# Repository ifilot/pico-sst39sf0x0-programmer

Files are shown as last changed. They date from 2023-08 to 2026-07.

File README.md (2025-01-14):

# PICO-SST39SF0x0 Programmer






OSHW (https://certification.oshwa.org/nl000020.html)

> [!NOTE]  
> Wish to buy an assembled device? Feel free to contact me at ivo@ivofilot.nl. Price will be around €20,00. Will ship from the Netherlands.

> [!TIP]
> There also exists [a command-line tool](https://github.com/ifilot/pico-flasher-cli) to interface with the PICO-SST39SF0x0 Programmer.

> [!CAUTION]  
> Whenever possible, avoid using USB hubs to connect your **PICO-SST39SF0x0 Programmer**. 
> USB hubs can sometimes cause instability in the serial connection, which may 
> lead to crashes or unexpected program behavior.

## Obtaining pre-built binaries

Download the latest version of the binaries via the links below.

* [Firmware PICO (.uf2 file)](https://github.com/ifilot/pico-sst39sf0x0-programmer/releases/latest/download/pico-sst39sf0x0-programmer-firmware.uf2)
* [Firmware PICO2 (.uf2 file)](https://github.com/ifilot/pico-sst39sf0x0-programmer/releases/latest/download/pico2-sst39sf0x0-programmer-firmware.uf2)
* [GUI Installer](https://github.com/ifilot/pico-sst39sf0x0-programmer/releases/latest/download/pico-sst39sf0x0-programmer-installer-win64.exe)

## Purpose

This open hardware project aims users to produce a low-cost flasher for the
[SST39SF0x0 type](https://ww1.microchip.com/downloads/en/DeviceDoc/20005022C.pdf) 
of ROM chips. The flasher revolves around the cheap
[Raspberry PICO](https://www.raspberrypi.com/products/raspberry-pi-pico/) device.

Besides general read/write/erase functionality for the SST39SF0x0 type of ROM
chips, the software and tools delivered with the PICO-SST39SF0x0 Programmer tend
to cater to a number of projects involving the venerable 
[P2000T and P2000M](https://en.wikipedia.org/wiki/Philips_P2000), both early 
Philips home computers of the 1980s. See the list below for the projects that
use the PICO-SST39SF0x0 Programmer flasher.

* [P2000T Cartridges](https://github.com/ifilot/p2000t-cartridges): A set of
  homebrew cartridges designed for the P2000T. These cartridges all use
  SST39SF0x0 type of ROM chips.
* C64 Multirom

Nevertheless, this is a general purpose product and you are able to flash and
kind of data onto the ROM chips.

> [!TIP]  
> If you do not like seeing these ROM files being displayed, you can hide them
> via `Edit > Settings`.

## Device

The fully assembled device will look as seen in the image below. A ZIF-style
socket is used to insert the SST39SF0x0 chip. A reset button button is exposed
which will reset the device. The green and red LEDs will be on during read and
write operations, respectively. At the top-right part of the device, an access
hole is made to insert a long thin wire to press on the `bootsel` button of the
Raspberry Pi PICO. When this button is pressed down and a USB cable is inserted,
the PICO will expose a file system allowing the user to upload the firmware
to the device.

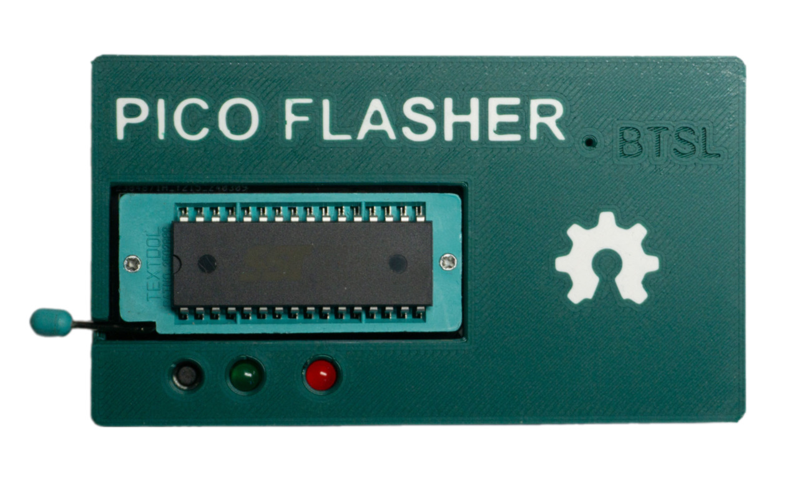
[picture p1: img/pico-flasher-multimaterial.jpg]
Image of the PICO Flasher device


Inside the enclosure is a single PCB that hosts the PICO, the ZIF cartridge
and a number of chips. Since the GPIO pins on the PICO are 3.3V, extensive use
of level shifters is made to hook up the PICO to the SST39SF0x0 chip, whose
pins operate at the 5V logic level. To set the address on the SST39SF0x0 chip,
three 74HC573 chips are being used (U2-U4). A diode (D1) acts as the reverse
polarity protection in the event the user would place the chip in the wrong
direction.

PCB frontside | PCB backside
------------- | ------------
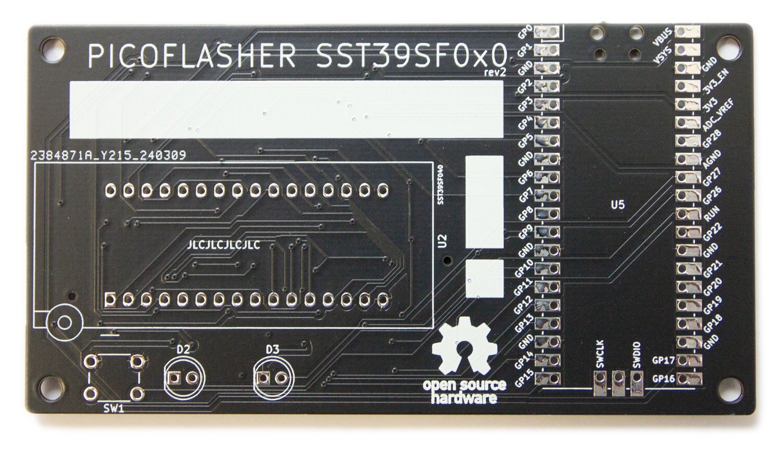
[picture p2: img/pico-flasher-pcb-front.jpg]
PCB frontside
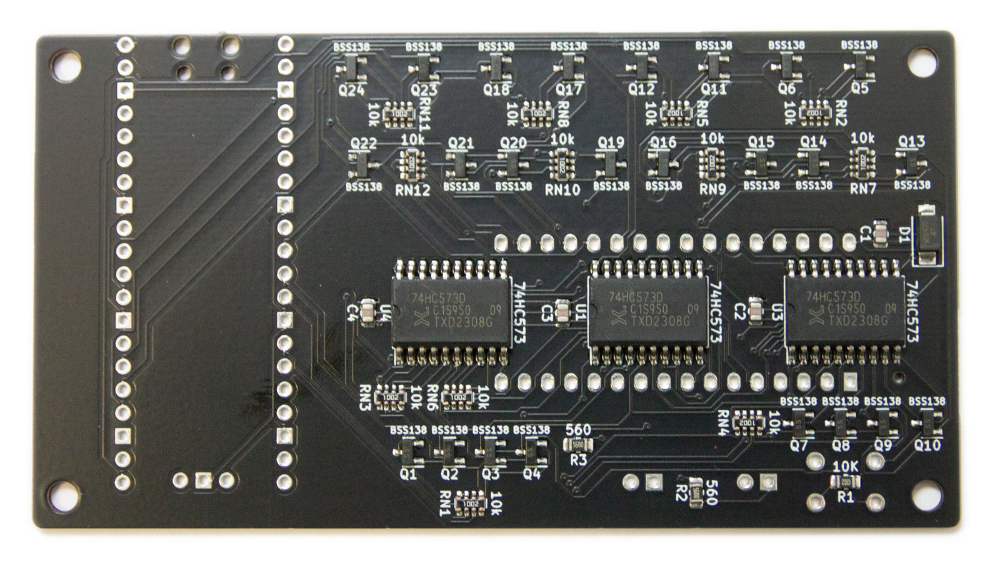
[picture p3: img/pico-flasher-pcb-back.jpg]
PCB backside
 | 

## GUI

To interface with the device, a GUI is written using the 
[Qt framework](https://www.qt.io/). The GUI scans for all USB devices connected
to the computer with a hardware signature matching the Raspberry Pi PICO. Upon
a match, it tries to access the device. Interfacing with the device occurs via
a [serial communication (COM) port](https://en.wikipedia.org/wiki/COM_(hardware_interface)).
By means of a number of [simple 8-byte command words](firmware/README.md),
instructions can be sent to the device and the corresponding response can be
received. One is not restricted to using the GUI to interface with the device.
An [example set of Python scripts](firmware/scripts) is provided to provide 
an alternative way to communicate with the PICO programmer.

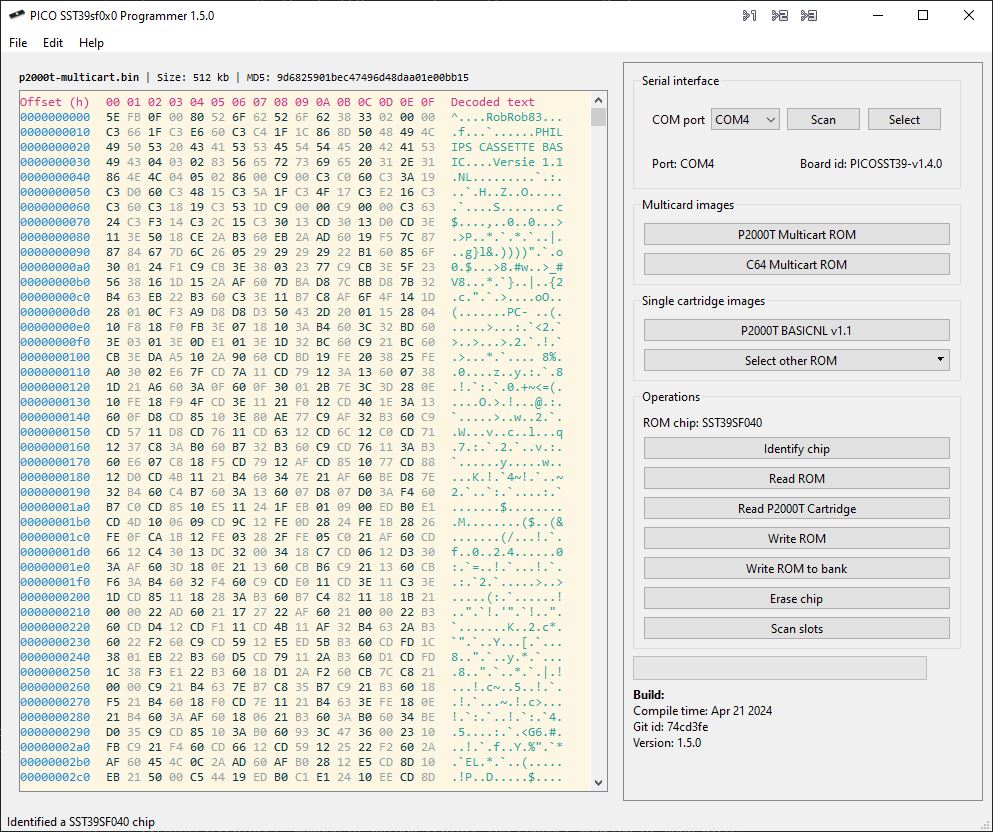
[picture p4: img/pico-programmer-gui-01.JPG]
PICO programmer GUI


> [!NOTE]  
> There is also a command-line tool available via
> [this repository](https://github.com/ifilot/pico-flasher-cli).

## Documentation and tutorials

A number of useful tutorials to work with the PICO programmer are provided
below.

* [Flashing the device / updating firmware](https://www.philips-p2000t.nl/tools/pico-sst39sf0x0-programmer.html#flashing-firmware-to-the-programmer)
* [Using the programmer to create copies of P2000T cartridges](https://www.philips-p2000t.nl/tools/pico-sst39sf0x0-programmer-slot1-adapter-board.html)
* [Using the PICO programmer in combination with the P2000T ZIF-cartridge](https://www.philips-p2000t.nl/cartridges/zif-cartridge.html#zif-cartridge)

## Schematics

PCB schematics

[Download schematics as PDF](pcb/pico-sst39sf0x0-pcb/pico-sst39sf0x0-pcb.pdf)

## Contents

* [Case](case): Set of .stl files to print a handy case for your flash device.
* [Firmware](firmware): Firmware for your PICO to interface with the GUI.
* [GUI](gui): Qt-based GUI to interface with your PICO.
* [PCB](pcb): Kicad files to produce the PICO flash device and the PLCC32 adapter board.
* [Scripts](scripts): Number of Python scripts the correct working of your PICO
  device.

## License

* All software is shared under the [GPL v3 license](https://www.gnu.org/licenses/gpl-3.0).
* All hardware (e.g. KiCAD files and .stl files) are shared under the [CC-BY-SA 4.0 license](https://creativecommons.org/licenses/by-sa/4.0/).

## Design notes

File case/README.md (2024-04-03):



# PICO-SST39SF0x0 Programmer Cases

This folder contains .stl files to create a nice 3d-printable case for your
rom flasher. The files are marked as `bottom` or `top` for the bottom and
top parts of the case. You will need 4xM3 screws to fasten everything together.

The STL files have cylinders (10mm width; 0.3mm height) attached to
the corners to prevent warping of the object upon printing. These spheres
are called [mouse ears](https://the3dprinterbee.com/mouse-ears-brim-ears/).

## Recommended printer settings

* Layer height: 0.15mm
* Infill: 20%
* Fill pattern: grid

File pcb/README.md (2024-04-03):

# PCBs



This folder contains three subfolders containing the KiCAD files for three
PCBs

* [pico-sst39sf0x0-pcb](pico-sst39sf0x0-pcb): Core PCB containing the Raspberry
  Pi PICO, the ZIF socket and the required interfacing circuitry.
* [p2000t-slot1-adapter-board](p2000t-slot1-adapter-board): Adapter board for
  non-invasive extraction of data from SLOT1 cartridges for the P2000T
* [plcc32-adapter-board](plcc32-adapter-board): Adapter board for interfacing
  the DIP32 SST39SF0x0 chips with the PLCC32 variant.

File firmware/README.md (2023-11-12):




# PICO Firmware

This folder contains the firmware for the PICO.

## Compilation

```
mkdir build-firmware
cd build-firmware
cmake ../firmware
make -j9
```

Next, copy the `sst39sf040.uf2` file from the `build` folder to your PICO.

## Toolchain

First install the following packages

```bash
sudo apt update
sudo apt install -y cmake gcc-arm-none-eabi libnewlib-arm-none-eabi \
build-essential libstdc++-arm-none-eabi-newlib
```

Next, install the toolchain

```bash
sudo git clone https://github.com/raspberrypi/pico-sdk.git /opt/pico-sdk
sudo git -C /opt/pico-sdk submodule update --init
echo 'export PICO_SDK_PATH=/opt/pico-sdk' | sudo tee -a /etc/profile.d/pico-sdk.sh
source /etc/profile
```

## UART commands

The PICO exposes a COM port for interdevice communication. All commands have a fixed
width of 8 characters, which is echoed back. Depending on the command, either the
PICO expects to receive another chunk of data or returns more output. The list
of commands are given below.

* `READINFO`: Reads the board ID. Returns 16 bytes of data.
* `RDBKXXXX`: Reads a block of data (256 bytes) at hex position `XXXX00`. Returns
  256 bytes of data.
* `RDSECTXX`: Reads a sector of data (4kb) at hex position `XX000`. Returns
  4kb bytes of data.
* `RDBANKXX`: Reads a bank of data (16kb) where `XX` corresponds to the
  bank id.
* `RP2KCRXX`: Reads a block of data (0x1000 bytes) at hex position `XX000`. Returns
  0x1000 bytes of data. This function is used to interface with the P2000T cartridge,
  do not use this function when reading from a regular ROM chip.
* `DEVIDSST`: Attempts to read the device ID of the SST39SF0x0 chip. Returns
  2 bytes of data.
* `WRBKXXXX`: Write a block of data at hex position `XXXX00`.
  Expects 256 bytes of data after the command echo. Returns 1 byte checksum.
* `WRSECTXX`: Writes a sector of data (4kb) at hex position `XX000`. Returns
  a CRC16 XMODEM checksum (2 bytes).
* `ESSTXXXX`: Erases a block of data (writing `0xFF`) at hex position `XXXX000`.
  Returns number of wait cycles as 16 bit signed integer.
* `ERASEALL`: Completely wipes the chip, writing `0xFF` to all bytes.
* `TESTTEST`: Simple test routine. Reads the first 32 bytes on the chip. Returns
  32 bytes of data.

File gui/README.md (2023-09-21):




# GUI

This folder contains the source files for building the GUI.

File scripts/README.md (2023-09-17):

# Scripts

This folder contains a number of Python scripts to test the PICO board. 

* interface-test.py: Test interfacing to the PICO board
* p2k-test.py: Test reading from a P2000T SLOT1 cartridge using the adapter board.
* read-test.py: Test reading from a SST39SF0x0 chip
* write-test.py: Test writing to a SST39SF0x0 chip

> [!IMPORTANT]  
> Please note that for many of these tests, the BASICNL v1.1 ROM is used. One
> either needs the original cartridge or a imitation to repeat upon these tests.
> Before execution of these tests, carefully read the test procedure and ensure
> that any used URLs are valid.

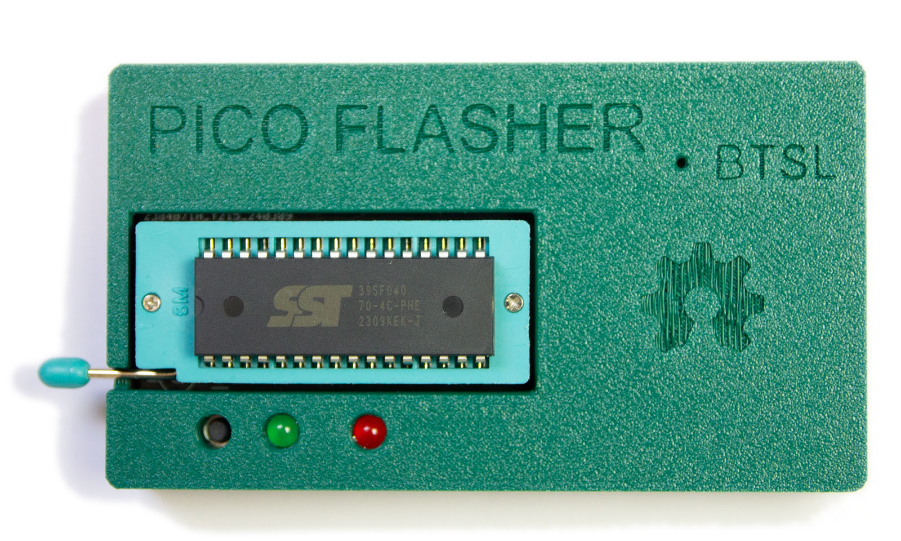
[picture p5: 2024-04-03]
img/pico-flasher.jpg

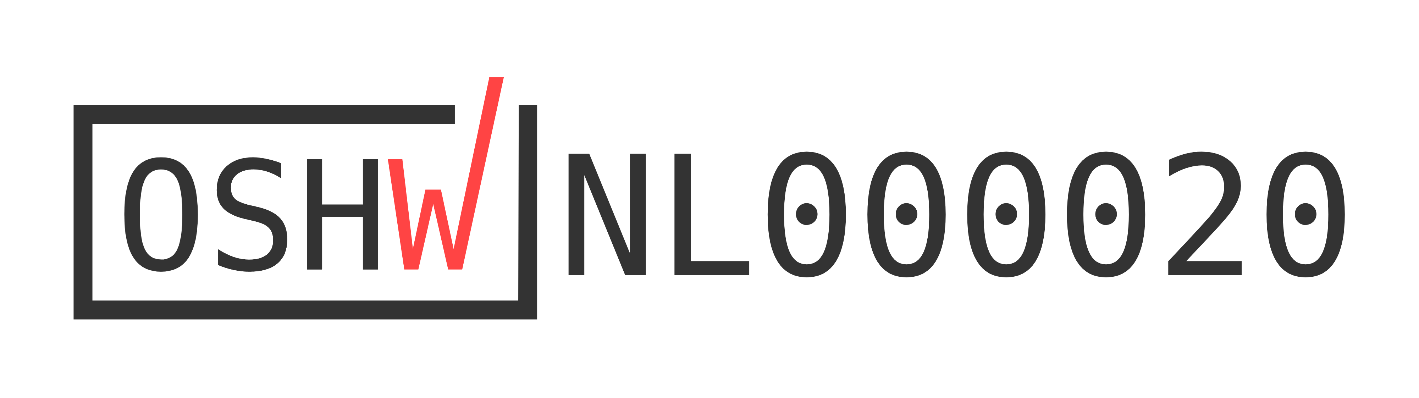
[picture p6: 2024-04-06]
img/certification-mark-NL000020-wide.png

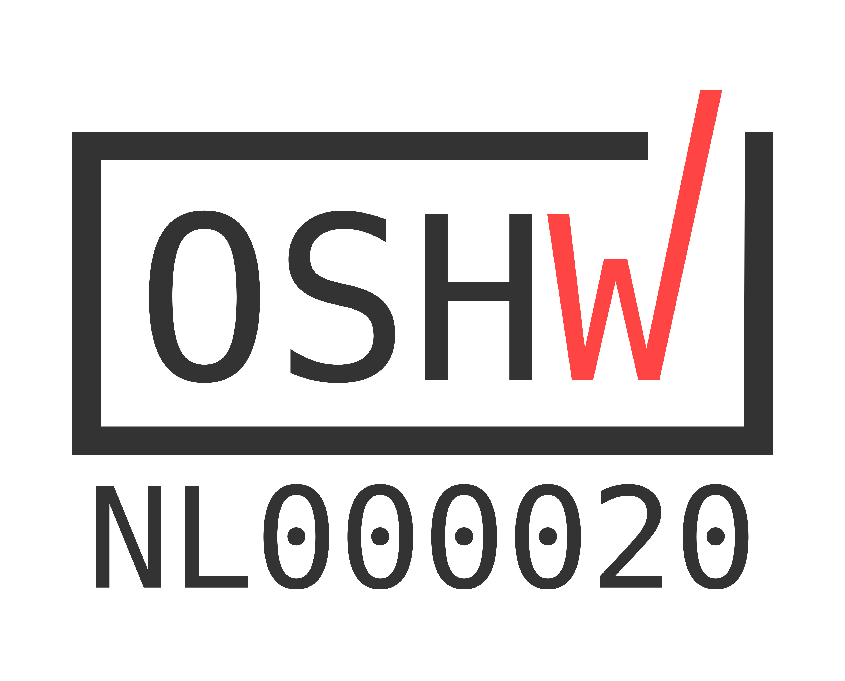
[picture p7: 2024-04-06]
img/certification-mark-NL000020-stacked.png

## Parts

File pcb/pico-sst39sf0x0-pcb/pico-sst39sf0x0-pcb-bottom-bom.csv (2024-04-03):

Comment | Designator | Footprint | LCSC Part #
.1uF Unpolarized capacitor | C1,C2,C3,C4 | C_0805_2012Metric | C1790
M7 Diode, small symbol | D1 | D_SMA | C95872
BSS138 50V Vds, 0.22A Id, N-Channel MOSFET, SOT-23 | Q1,Q2,Q3,Q4,Q5,Q6,Q7,Q8,Q9,Q10,Q11,Q12,Q13,Q14,Q15,Q16,Q17,Q18,Q19,Q20,Q21,Q22,Q23,Q24 | SOT-23 | C78284
10K Resistor | R1 | R_0805_2012Metric_Pad1.20x1.40mm_HandSolder | C17414
560 Resistor | R2,R3 | R_0805_2012Metric_Pad1.20x1.40mm_HandSolder | C28636
10k 4 resistor network, parallel topology, split | RN1,RN2,RN3,RN4,RN5,RN6,RN7,RN8,RN9,RN10,RN11,RN12 | R_Array_Convex_4x0603 | C110924
74HC573 8-bit Latch 3-state outputs | U1,U3,U4 | SOIC-20W_7.5x12.8mm_P1.27mm | C5608

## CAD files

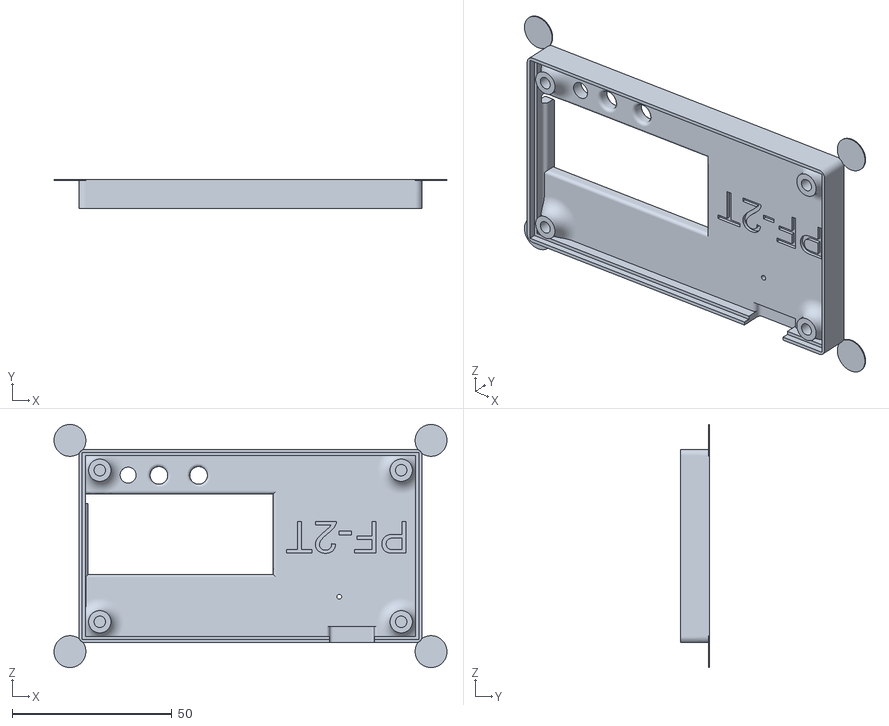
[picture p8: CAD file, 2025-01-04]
case/multi-material/pico-case-top-36.stl
123.2 x 9.00 x 76.2

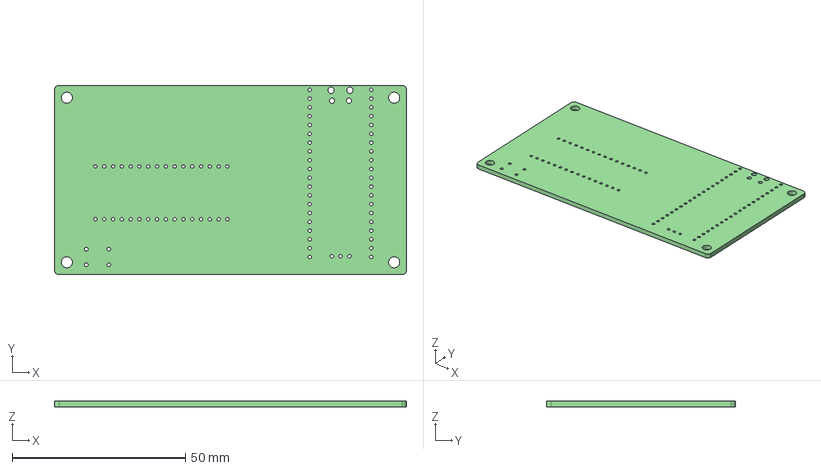
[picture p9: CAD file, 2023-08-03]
pcb/pico-sst39sf0x0-pcb/pico-sst39sf0x0-pcb.step
101.6 x 54.6 x 1.60 mm

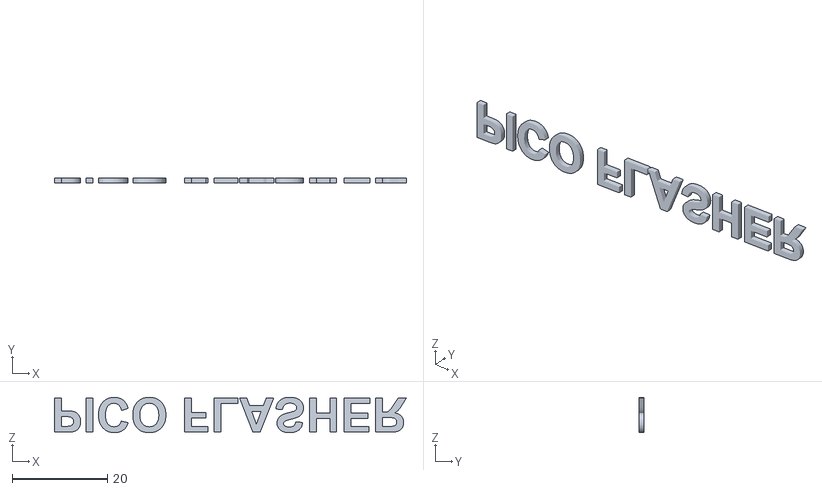
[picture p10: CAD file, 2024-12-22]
case/multi-material/pico-label.stl
74.1 x 1.00 x 7.45

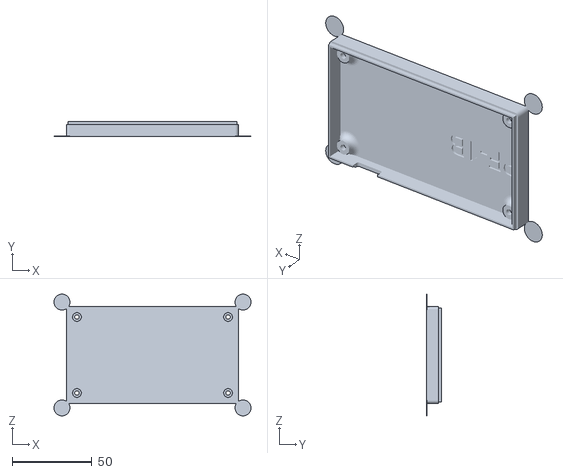
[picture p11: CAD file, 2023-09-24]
case/single/pico-case-bottom_mouse_ears.stl
123.2 x 9.60 x 76.2

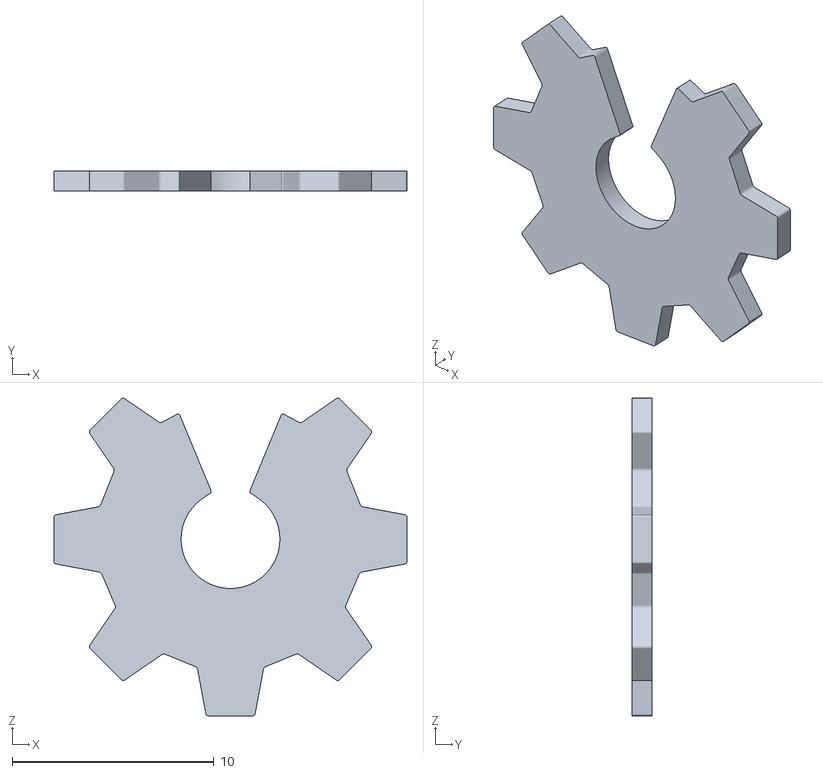
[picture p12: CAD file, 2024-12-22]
case/multi-material/pico-oshw-logo.stl
17.5 x 1.00 x 15.7

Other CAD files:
case/single/pico-case-top_mouse_ears.stl
case/multi-material/pico-case-top.stl
case/multi-material/pico-case-bottom.stl

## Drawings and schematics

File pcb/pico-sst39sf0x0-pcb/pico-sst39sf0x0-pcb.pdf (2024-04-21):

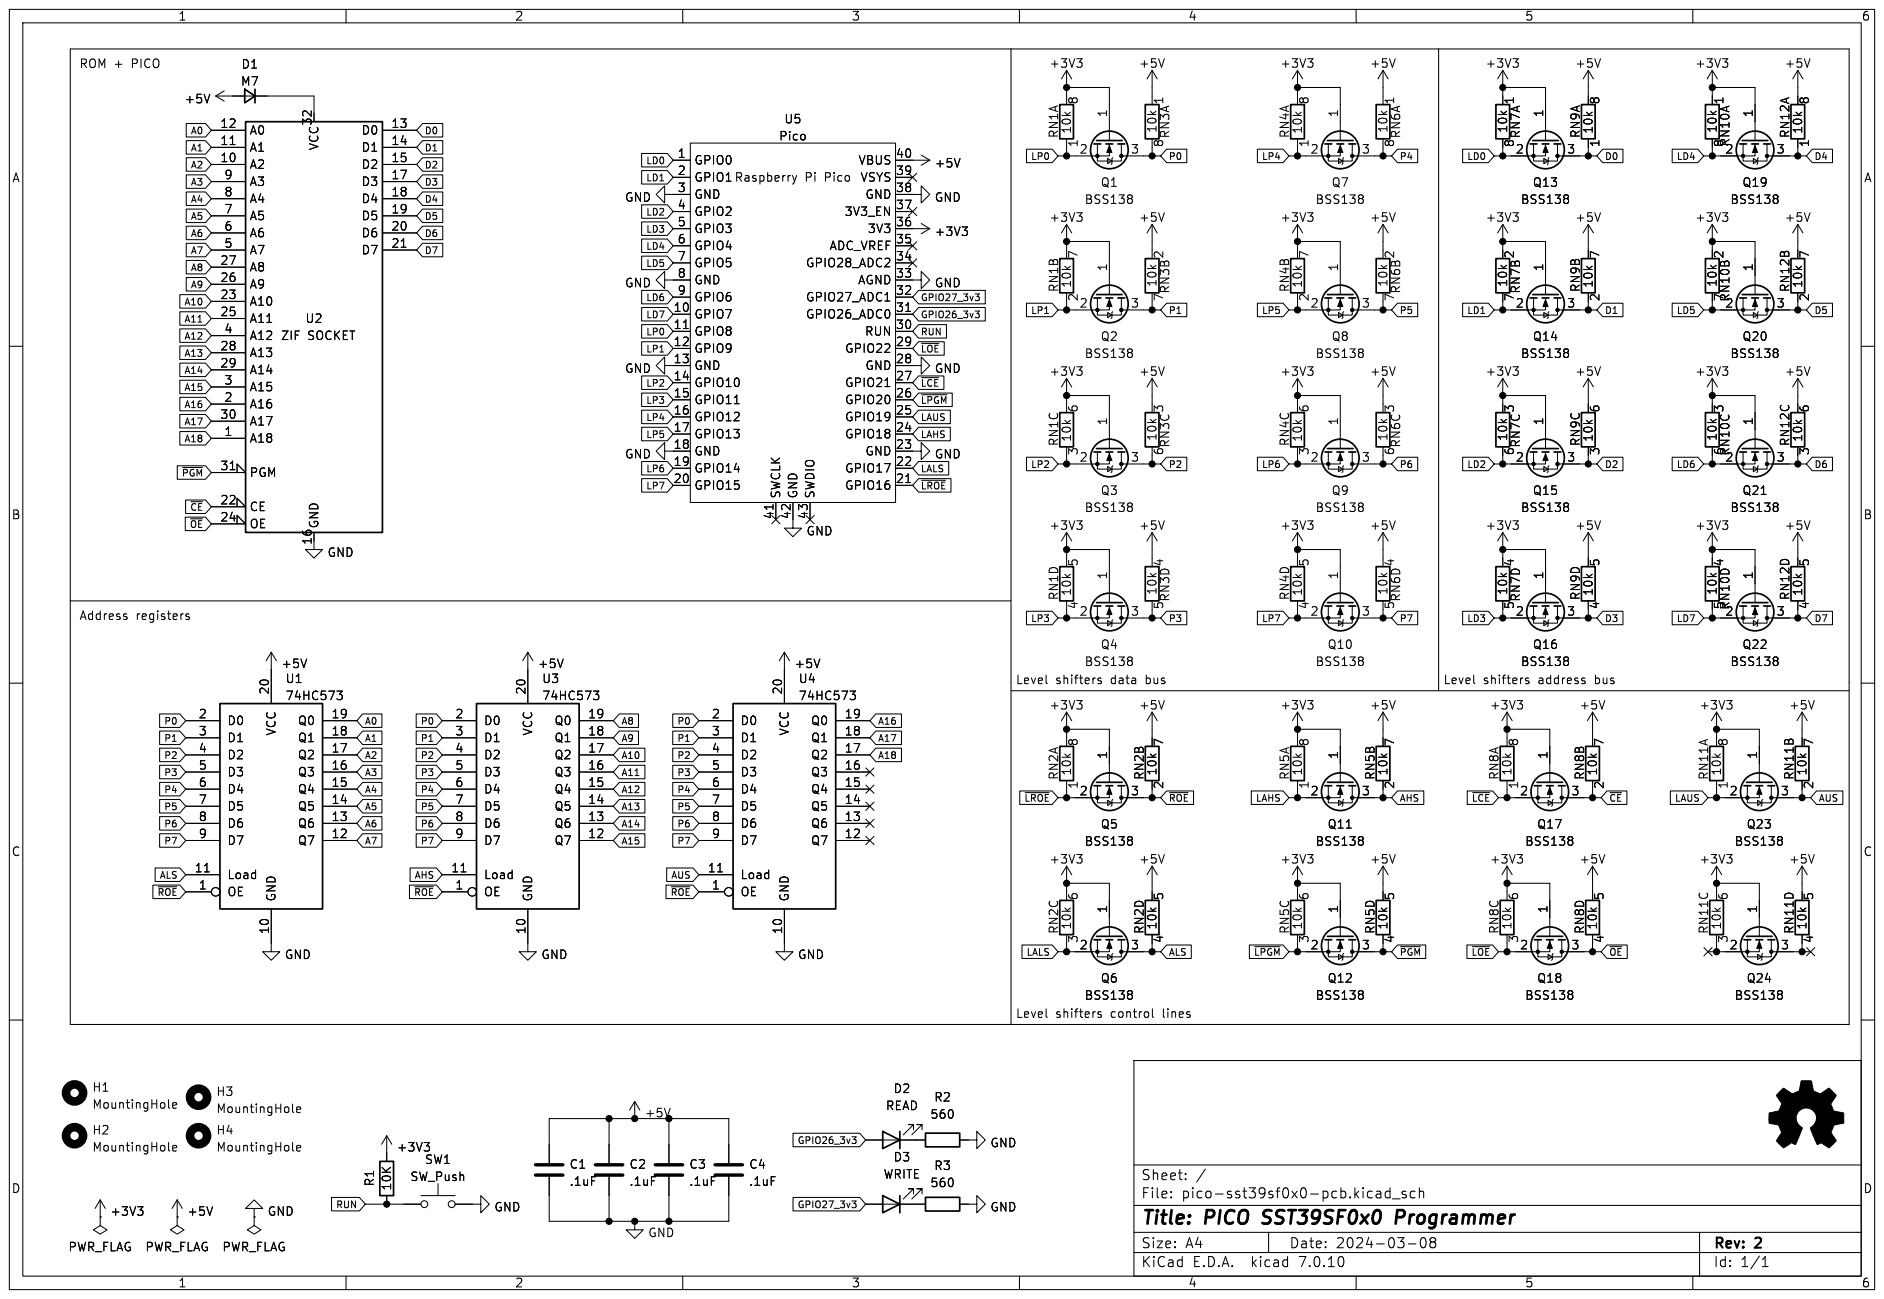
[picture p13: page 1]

GND GND

Id: 1/1 Title: PICO SST39SF0x0 Programmer File: pico-sst39sf0x0-pcb.kicad_sch Sheet: /

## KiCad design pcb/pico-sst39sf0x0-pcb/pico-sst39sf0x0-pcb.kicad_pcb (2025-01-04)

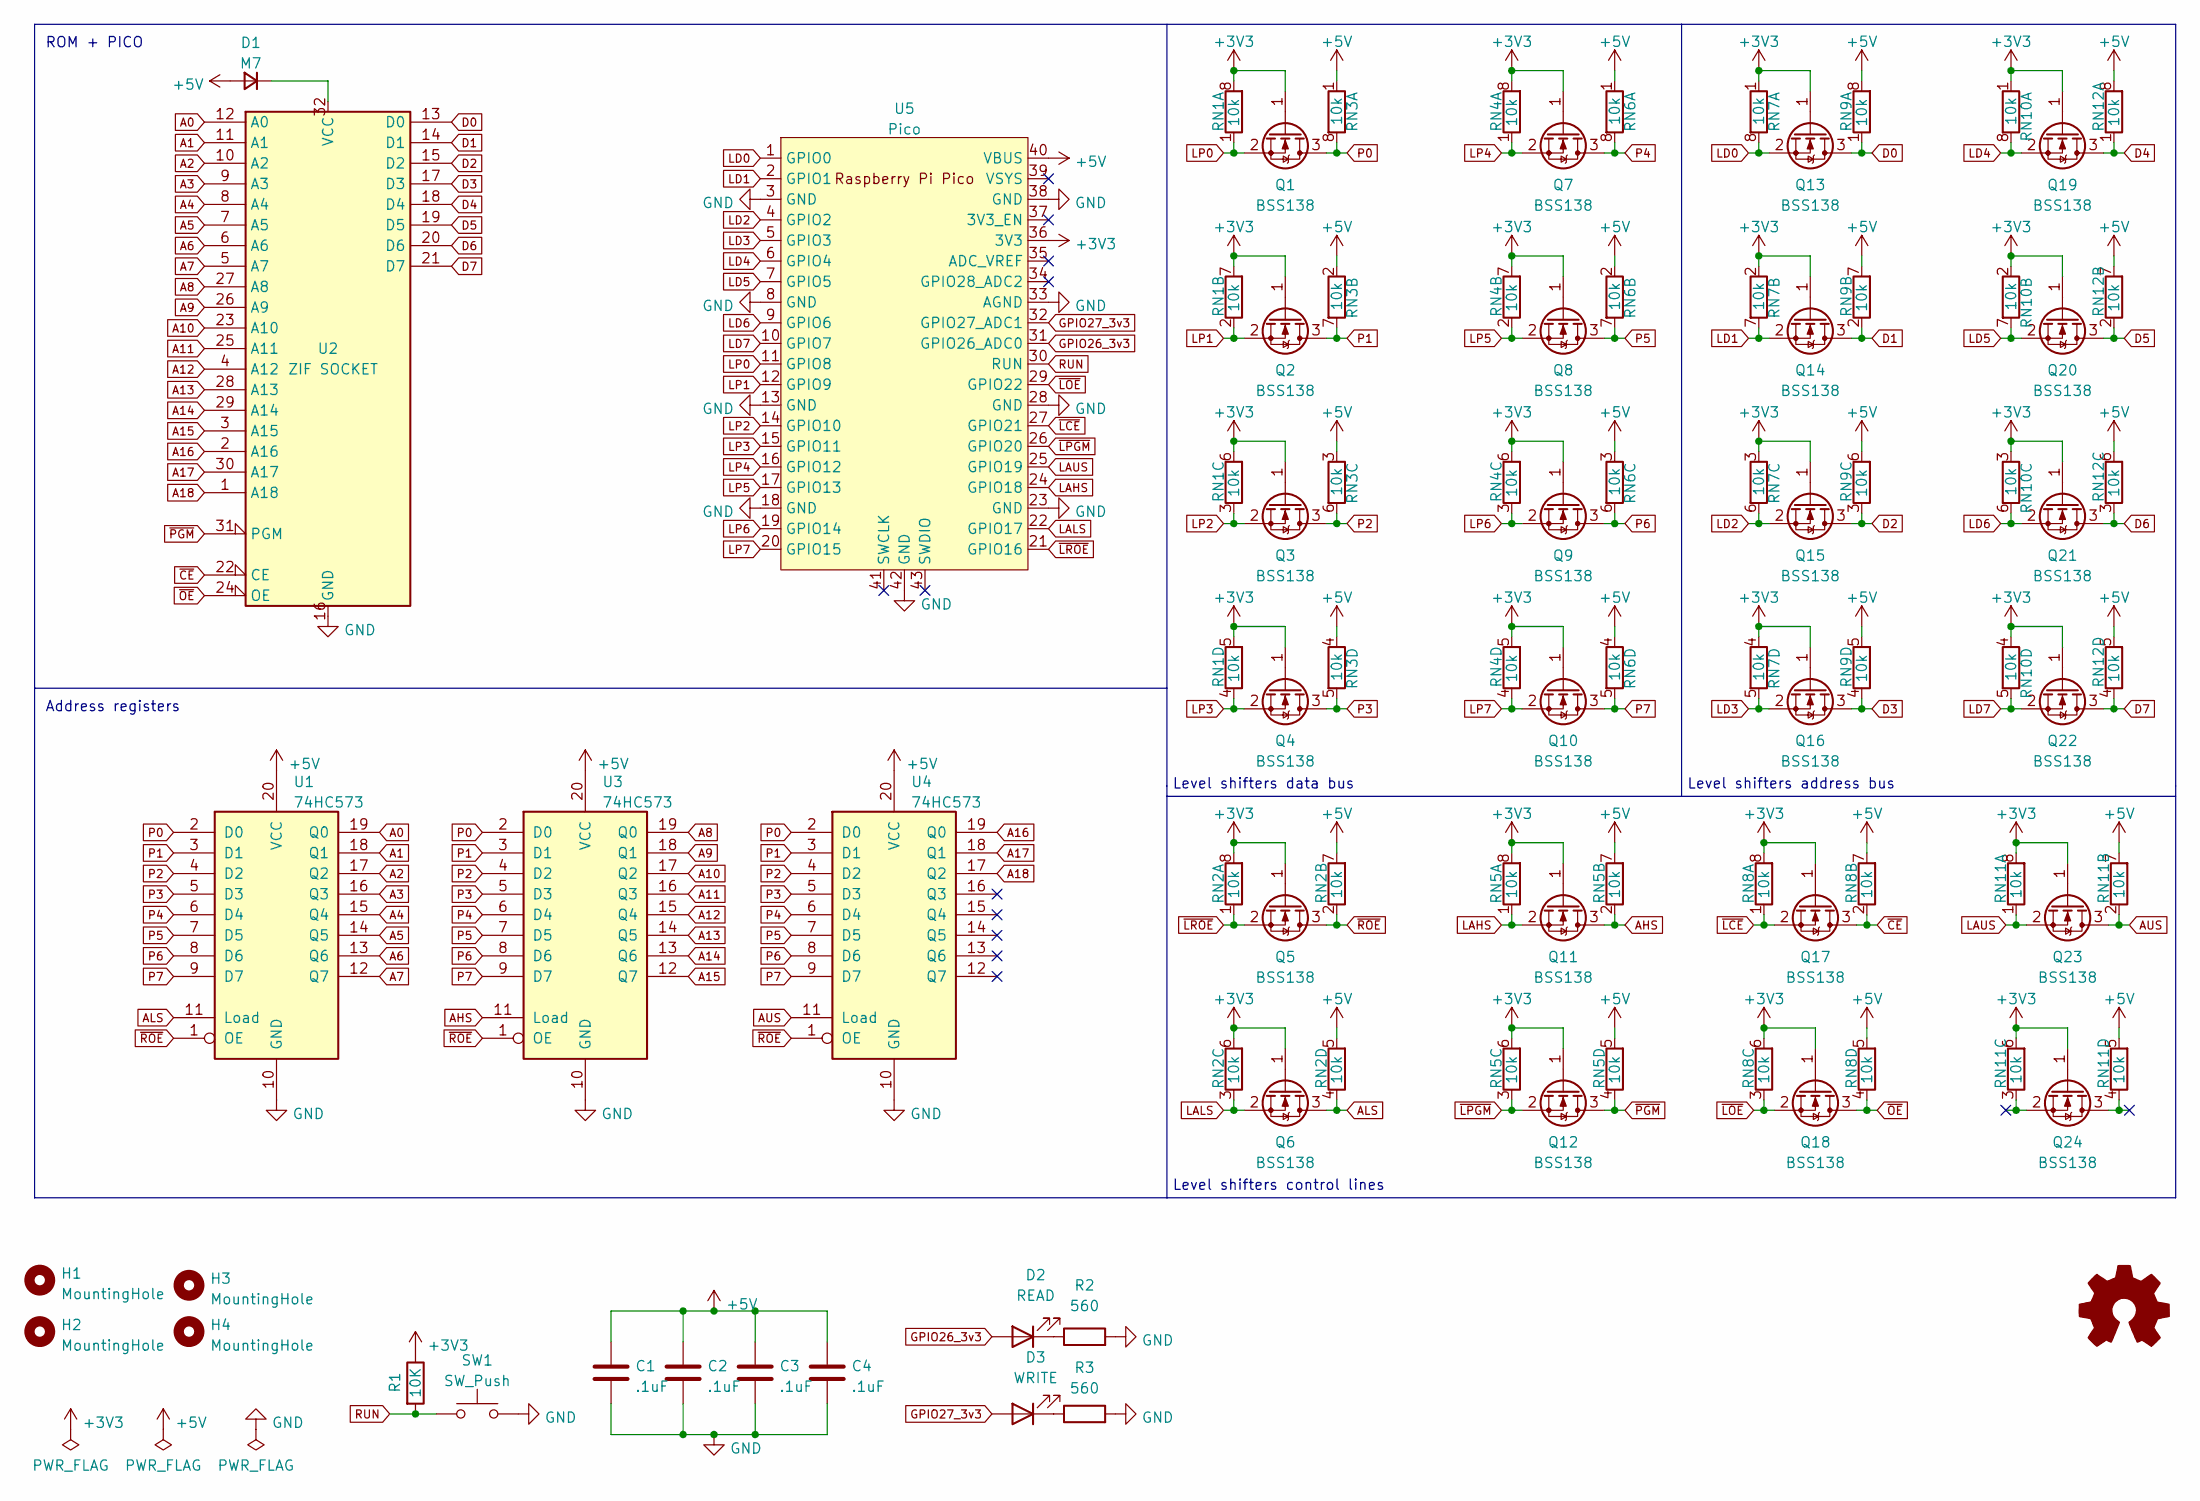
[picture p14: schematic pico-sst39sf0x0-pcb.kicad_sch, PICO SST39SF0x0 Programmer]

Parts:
C1, C2, C3, C4: .1uF; C_0805_2012Metric; LCSC C1790
D1: M7; D_SMA; LCSC C95872
D2: READ; LED_D5.0mm
D3: WRITE; LED_D5.0mm
G1: Logo_Open_Hardware_Small; OSHW-Logo_11.4x12mm_SilkScreen
H1, H2, H3, H4: MountingHole; MountingHole_3.2mm_M3
Q1, Q2, Q3, Q4, Q5, Q6, Q7, Q8, Q9, Q10, Q11, Q12, Q13, Q14, Q15, Q16, Q17, Q18, Q19, Q20, Q21, Q22, Q23, Q24: BSS138; SOT-23; LCSC C78284
R1: 10K; R_0805_2012Metric_Pad1.20x1.40mm_HandSolder; LCSC C17414
R2, R3: 560; R_0805_2012Metric_Pad1.20x1.40mm_HandSolder; LCSC C28636
RN1, RN2, RN3, RN4, RN5, RN6, RN7, RN8, RN9, RN10, RN11, RN12: 10k; R_Array_Convex_4x0603; LCSC C110924
SW1: SW_Push; SW_PUSH_6mm
U1, U3, U4: 74HC573; SOIC-20W_7.5x12.8mm_P1.27mm; LCSC C5608
U2: ZIF SOCKET; DIP_Socket-32_W11.9_W12.7_W15.24_W17.78_W18.5_3M_232-1285-0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
U5: Pico; RPi_Pico_SMD_TH

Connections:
+3V3: Q1.1 (G), Q2.1 (G), Q3.1 (G), Q4.1 (G), Q5.1 (G), Q6.1 (G), Q7.1 (G), Q8.1 (G), Q9.1 (G), Q10.1 (G), Q11.1 (G), Q12.1 (G), Q13.1 (G), Q14.1 (G), Q15.1 (G), Q16.1 (G), Q17.1 (G), Q18.1 (G), Q19.1 (G), Q20.1 (G), Q21.1 (G), Q22.1 (G), Q23.1 (G), Q24.1 (G), R1.1, RN1.5 (R4.2), RN1.6 (R3.2), RN1.7 (R2.2), RN1.8 (R1.2), RN2.6 (R3.2), RN2.8 (R1.2), RN4.5 (R4.2), RN4.6 (R3.2), RN4.7 (R2.2), RN4.8 (R1.2), RN5.6 (R3.2), RN5.8 (R1.2), RN7.1 (R1.1), RN7.2 (R2.1), RN7.3 (R3.1), RN7.4 (R4.1), RN8.6 (R3.2), RN8.8 (R1.2), RN10.1 (R1.1), RN10.2 (R2.1), RN10.3 (R3.1), RN10.4 (R4.1), RN11.6 (R3.2), RN11.8 (R1.2), U5.36 (3V3)
+5V: C1.1, C2.1, C3.1, C4.1, D1.2 (A), RN2.5 (R4.2), RN2.7 (R2.2), RN3.1 (R1.1), RN3.2 (R2.1), RN3.3 (R3.1), RN3.4 (R4.1), RN5.5 (R4.2), RN5.7 (R2.2), RN6.1 (R1.1), RN6.2 (R2.1), RN6.3 (R3.1), RN6.4 (R4.1), RN8.5 (R4.2), RN8.7 (R2.2), RN9.5 (R4.2), RN9.6 (R3.2), RN9.7 (R2.2), RN9.8 (R1.2), RN11.5 (R4.2), RN11.7 (R2.2), RN12.5 (R4.2), RN12.6 (R3.2), RN12.7 (R2.2), RN12.8 (R1.2), U1.20 (VCC), U3.20 (VCC), U4.20 (VCC), U5.40 (VBUS)
A0: U1.19 (Q0), U2.12 (A0)
A1: U1.18 (Q1), U2.11 (A1)
A2: U1.17 (Q2), U2.10 (A2)
A3: U1.16 (Q3), U2.9 (A3)
A4: U1.15 (Q4), U2.8 (A4)
A5: U1.14 (Q5), U2.7 (A5)
A6: U1.13 (Q6), U2.6 (A6)
A7: U1.12 (Q7), U2.5 (A7)
A8: U2.27 (A8), U3.19 (Q0)
A9: U2.26 (A9), U3.18 (Q1)
A10: U2.23 (A10), U3.17 (Q2)
A11: U2.25 (A11), U3.16 (Q3)
A12: U2.4 (A12), U3.15 (Q4)
A13: U2.28 (A13), U3.14 (Q5)
A14: U2.29 (A14), U3.13 (Q6)
A15: U2.3 (A15), U3.12 (Q7)
A16: U2.2 (A16), U4.19 (Q0)
A17: U2.30 (A17), U4.18 (Q1)
A18: U2.1 (A18), U4.17 (Q2)
AHS: Q11.3 (D), RN5.2 (R2.1), U3.11 (Load)
ALS: Q6.3 (D), RN2.4 (R4.1), U1.11 (Load)
AUS: Q23.3 (D), RN11.2 (R2.1), U4.11 (Load)
D0: Q13.3 (D), RN9.1 (R1.1), U2.13 (D0)
D1: Q14.3 (D), RN9.2 (R2.1), U2.14 (D1)
D2: Q15.3 (D), RN9.3 (R3.1), U2.15 (D2)
D3: Q16.3 (D), RN9.4 (R4.1), U2.17 (D3)
D4: Q19.3 (D), RN12.1 (R1.1), U2.18 (D4)
D5: Q20.3 (D), RN12.2 (R2.1), U2.19 (D5)
D6: Q21.3 (D), RN12.3 (R3.1), U2.20 (D6)
D7: Q22.3 (D), RN12.4 (R4.1), U2.21 (D7)
GND: C1.2, C2.2, C3.2, C4.2, R2.2, R3.2, SW1.2, U1.10 (GND), U2.16 (GND), U3.10 (GND), U4.10 (GND), U5.3 (GND), U5.8 (GND), U5.13 (GND), U5.18 (GND), U5.23 (GND), U5.28 (GND), U5.33 (AGND), U5.38 (GND), U5.42 (GND)
GPIO26_3v3: D2.2 (A), U5.31 (GPIO26_ADC0)
GPIO27_3v3: D3.2 (A), U5.32 (GPIO27_ADC1)
LAHS: Q11.2 (S), RN5.1 (R1.1), U5.24 (GPIO18)
LALS: Q6.2 (S), RN2.3 (R3.1), U5.22 (GPIO17)
LAUS: Q23.2 (S), RN11.1 (R1.1), U5.25 (GPIO19)
LD0: Q13.2 (S), RN7.8 (R1.2), U5.1 (GPIO0)
LD1: Q14.2 (S), RN7.7 (R2.2), U5.2 (GPIO1)
LD2: Q15.2 (S), RN7.6 (R3.2), U5.4 (GPIO2)
LD3: Q16.2 (S), RN7.5 (R4.2), U5.5 (GPIO3)
LD4: Q19.2 (S), RN10.8 (R1.2), U5.6 (GPIO4)
LD5: Q20.2 (S), RN10.7 (R2.2), U5.7 (GPIO5)
LD6: Q21.2 (S), RN10.6 (R3.2), U5.9 (GPIO6)
LD7: Q22.2 (S), RN10.5 (R4.2), U5.10 (GPIO7)
LP0: Q1.2 (S), RN1.1 (R1.1), U5.11 (GPIO8)
LP1: Q2.2 (S), RN1.2 (R2.1), U5.12 (GPIO9)
LP2: Q3.2 (S), RN1.3 (R3.1), U5.14 (GPIO10)
LP3: Q4.2 (S), RN1.4 (R4.1), U5.15 (GPIO11)
LP4: Q7.2 (S), RN4.1 (R1.1), U5.16 (GPIO12)
LP5: Q8.2 (S), RN4.2 (R2.1), U5.17 (GPIO13)
LP6: Q9.2 (S), RN4.3 (R3.1), U5.19 (GPIO14)
LP7: Q10.2 (S), RN4.4 (R4.1), U5.20 (GPIO15)
unnamed: D1.1 (K), U2.32 (VCC)
unnamed: D2.1 (K), R2.1
unnamed: D3.1 (K), R3.1
P0: Q1.3 (D), RN3.8 (R1.2), U1.2 (D0), U3.2 (D0), U4.2 (D0)
P1: Q2.3 (D), RN3.7 (R2.2), U1.3 (D1), U3.3 (D1), U4.3 (D1)
P2: Q3.3 (D), RN3.6 (R3.2), U1.4 (D2), U3.4 (D2), U4.4 (D2)
P3: Q4.3 (D), RN3.5 (R4.2), U1.5 (D3), U3.5 (D3), U4.5 (D3)
P4: Q7.3 (D), RN6.8 (R1.2), U1.6 (D4), U3.6 (D4), U4.6 (D4)
P5: Q8.3 (D), RN6.7 (R2.2), U1.7 (D5), U3.7 (D5), U4.7 (D5)
P6: Q9.3 (D), RN6.6 (R3.2), U1.8 (D6), U3.8 (D6), U4.8 (D6)
P7: Q10.3 (D), RN6.5 (R4.2), U1.9 (D7), U3.9 (D7), U4.9 (D7)
RUN: R1.2, SW1.1, U5.30 (RUN)
~CE: Q17.3 (D), RN8.2 (R2.1), U2.22 (CE)
~LCE: Q17.2 (S), RN8.1 (R1.1), U5.27 (GPIO21)
~LOE: Q18.2 (S), RN8.3 (R3.1), U5.29 (GPIO22)
~LPGM: Q12.2 (S), RN5.3 (R3.1), U5.26 (GPIO20)
~LROE: Q5.2 (S), RN2.1 (R1.1), U5.21 (GPIO16)
~OE: Q18.3 (D), RN8.4 (R4.1), U2.24 (OE)
~PGM: Q12.3 (D), RN5.4 (R4.1), U2.31 (PGM)
~ROE: Q5.3 (D), RN2.2 (R2.1), U1.1 (OE), U3.1 (OE), U4.1 (OE)

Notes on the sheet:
Level shifters control lines
Level shifters data bus
Level shifters address bus
ROM + PICO
Address registers

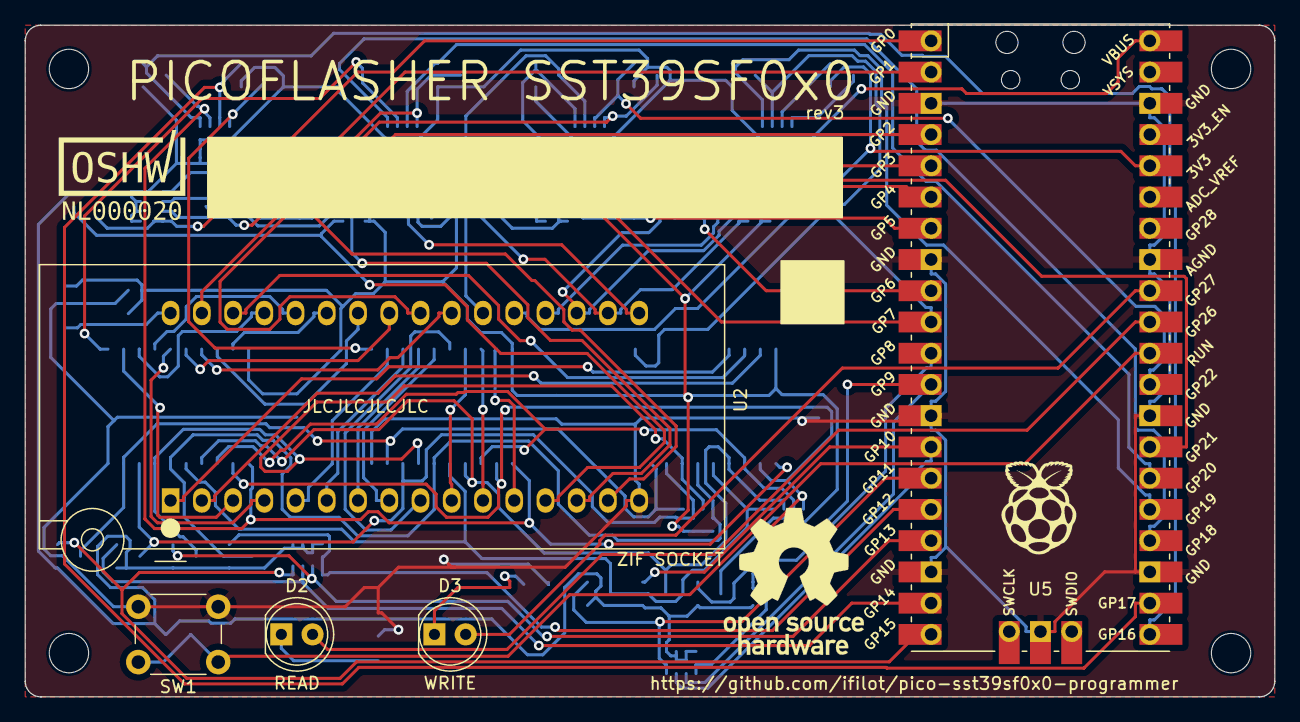
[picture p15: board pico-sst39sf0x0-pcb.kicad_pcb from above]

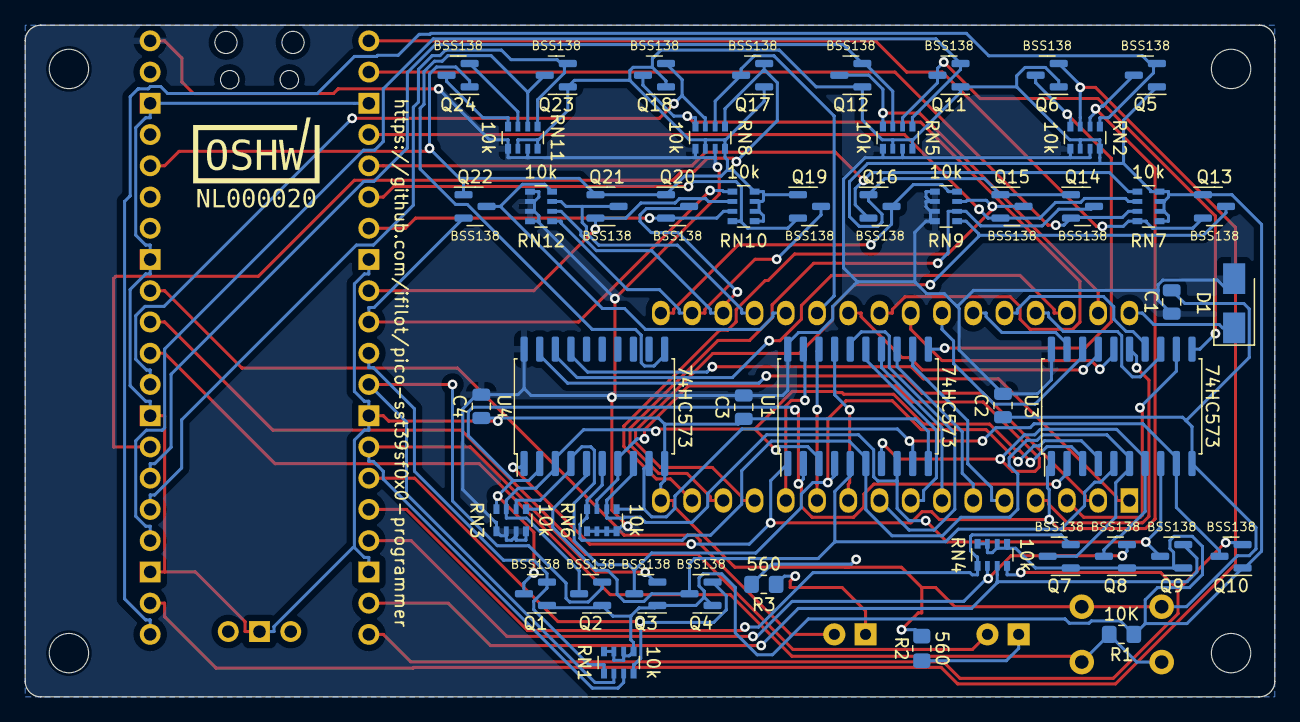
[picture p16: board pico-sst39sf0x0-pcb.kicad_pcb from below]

Board: 2 copper layers, 101.6 x 54.6 mm, 60 parts (48 on the bottom side), 74 nets.

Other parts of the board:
G1#2: Logo_Open_Hardware_Small; OSHW-Logo_11.4x12mm_SilkScreen
G1#3: LOGO; oshw_certificate_stacked
G4: LOGO; raspberry_pi_logo

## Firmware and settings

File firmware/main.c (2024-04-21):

/****************************************************************************
 *                                                                          *
 *   PICO-SST39SF0x0-FLASHER-FIRMWARE                                       *
 *   Copyright (C) 2023 Ivo Filot <ivo@ivofilot.nl>                         *
 *                                                                          *
 *   This program is free software: you can redistribute it and/or modify   *
 *   it under the terms of the GNU Lesser General Public License as         *
 *   published by the Free Software Foundation, either version 3 of the     *
 *   License, or (at your option) any later version.                        *
 *                                                                          *
 *   This program is distributed in the hope that it will be useful,        *
 *   but WITHOUT ANY WARRANTY; without even the implied warranty of         *
 *   MERCHANTABILITY or FITNESS FOR A PARTICULAR PURPOSE.  See the          *
 *   GNU General Public License for more details.                           *
 *                                                                          *
 *   You should have received a copy of the GNU General Public license      *
 *   along with this program.  If not, see <https://www.gnu.org/licenses/>. *
 *                                                                          *
 ****************************************************************************/

#include "constants.h"
#include <stdio.h>
#include <stdlib.h>
#include <string.h>
#include <pico/stdlib.h>
#include <tusb.h>

#include "routines.h"
#include "cmds.h"

// command storage
char instruction[9];    // stores single 8-byte instruction
uint8_t inptr = 0;      // instruction pointer
uint8_t buf[64];        // usb buffer

// forward declarations
void parse_instructions();

/**
 * Initialization routine that sets default pin configuration
 **/
void init() {
    // initialize standard I/O
    stdio_init_all();

    // initialize TinyUSB stack
    tusb_init();

    // initialize GPIO0-GPIO19 + 26,27
    gpio_init_mask(0x00CFFFFFF);

    // set GPIO8-GPIO23 + 26,27 to output and GPIO0-7 to input
    gpio_set_dir_out_masked(0x0CFFFF00);
    gpio_set_dir_in_masked(0x000000FF);

    // set output enable (~OE) line to high
    gpio_put(ROE, false);
    gpio_put(CE, true);
    gpio_put(OE, true);
    gpio_put(PGM, true);
    gpio_put(ALS, false);
    gpio_put(AHS, false);
    gpio_put(AUS, false);

    // set leds to output
    gpio_put(LED_RD, false);
    gpio_put(LED_WR, false);
}

/*
 * @brief Main routine
 */
int main() {
    init();

    while(true) {

        if (tud_cdc_connected()) {
            if (tud_cdc_available()) {
                char c = tud_cdc_read_char();
        
                // only capture alphanumerical data
                if((c >= 48 && c <= 57) || (c >= 65 && c <=90)) {
                    instruction[inptr] = c;
                    inptr++;
                }
                
                if(inptr == 8) {
                    parse_instructions();
                    inptr = 0;
                }
            }
        }

        tud_task();
    }
}

/*
 * @brief parse instructions received over serial
 */
void parse_instructions() {
    echo_command(instruction, 8);
    
    /*
    * Read identifier string from board
    */
    if(check_command(instruction, "READINFO", 0, 8)) {
        write_board_id();
        return;
    /*
    * Perform a simple test; reads the first 32 bytes of the ROM
    */
    } else if(check_command(instruction, "TESTTEST", 0, 8)) {
        printbytes32();
        return;
    /*
    * Read the device id from the SSTSF390x0 chip
    */
    } else if(check_command(instruction, "DEVIDSST", 0, 8)) {
        read_chip_id();
        return;
    /*
    * Completely erase the chip
    */
    } else if(check_command(instruction, "ERASEALL", 0, 8)) {
        erase_chip();
        return;
    /*
    * Read data from P2000 SLOT1 cartridge, requiring adapter board
    */        
    } else if(check_command(instruction, "RP2KCR", 0, 6)) {
        read_p2k_cartridge_block(get_uint8(instruction, 6));
        return;
    /*
    * Read a bank (16kb)
    */
    } else if(check_command(instruction, "RDBANK", 0, 6)) {
        read_bank(get_uint8(instruction, 6));
        return;
    /*
    * Read a block
    */
    } else if(check_command(instruction, "RDBK", 0, 4)) {
        read_block(get_uint16(instruction, 4));
        return;
    /*
    * Read a sector (4kb)
    */
    } else if(check_command(instruction, "RDSECT", 0, 6)) {
        read_sector(get_uint8(instruction, 6));
        return;
    /*
    * Write a sector (4kb)
    */
    } else if(check_command(instruction, "WRSECT", 0, 6)) {
        write_sector(get_uint8(instruction, 6));
        return;
    /*
    * Write a block (256 bytes)
    */
    } else if(check_command(instruction, "WRBK", 0, 4)) {
        write_block(get_uint16(instruction, 4));
        return;
    /*
    * Erase a sector (4kb)
    */
    } else if(check_command(instruction, "ESST", 0, 4)) {
        erase_sector(get_uint16(instruction, 4));
        return;
    }
}

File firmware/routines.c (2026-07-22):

/****************************************************************************
 *                                                                          *
 *   PICO-SST39SF0x0-FLASHER-FIRMWARE                                       *
 *   Copyright (C) 2023 Ivo Filot <ivo@ivofilot.nl>                         *
 *                                                                          *
 *   This program is free software: you can redistribute it and/or modify   *
 *   it under the terms of the GNU Lesser General Public License as         *
 *   published by the Free Software Foundation, either version 3 of the     *
 *   License, or (at your option) any later version.                        *
 *                                                                          *
 *   This program is distributed in the hope that it will be useful,        *
 *   but WITHOUT ANY WARRANTY; without even the implied warranty of         *
 *   MERCHANTABILITY or FITNESS FOR A PARTICULAR PURPOSE.  See the          *
 *   GNU General Public License for more details.                           *
 *                                                                          *
 *   You should have received a copy of the GNU General Public license      *
 *   along with this program.  If not, see <https://www.gnu.org/licenses/>. *
 *                                                                          *
 ****************************************************************************/

#include "routines.h"

/*
 * Write a full buffer over CDC, looping until every byte is actually queued/sent.
 * Return false if the host disconnects before the transfer completes.
 */
static bool write_all(const uint8_t *data, uint32_t len) {
    uint32_t written = 0;
    while (written < len) {
        if(!tud_cdc_connected()) {
            return false;
        }

        written += tud_cdc_write(data + written, len - written);
        tud_cdc_write_flush();
        tud_task();
    }

    return true;
}

/*
 * Read device ID and print it to console
 */
void read_chip_id() {
    gpio_put(LED_RD, true);

    write_byte(0x5555, 0xAA);
    write_byte(0x2AAA, 0x55);
    write_byte(0x5555, 0x90);

    uint8_t id1 = read_byte(0x0000);
    uint8_t id2 = read_byte(0x0001);

    write_byte(0x5555, 0xAA);
    write_byte(0x2AAA, 0x55);
    write_byte(0x5555, 0xF0);

    gpio_put(LED_RD, false);

    tud_cdc_write_char(id1);
    tud_cdc_write_char(id2);
    tud_cdc_write_flush();
}

/*
 * Print data for first 32 bytes on chip
 */
void printbytes32() {
    for(uint32_t addr = 0; addr < 32; addr++) {
        if(addr == 16) {
            printf("\n");
        }
        
        uint8_t val = read_byte(addr);
        printf("%02X ", val);
    }
    printf("\n\n");
}

/*
 * @brief Read block of 256 bytes
 *
 * sector_addr: upper bytes
 */
void read_block(uint32_t block_id) {
    gpio_put(LED_RD, true);

    // set pins 0-7 to input
    gpio_set_dir_in_masked(0x000000FF);
    
    // bitshift to get full address
    uint32_t sector_addr = block_id << 8;
    set_address(sector_addr);

    // data buffer
    uint8_t data[0x100];

    // enable chip
    gpio_put(CE, false);

    // set address to read from
    for(uint32_t i=0; i<256; i++) {
        set_address_low(i);
    
        gpio_put(OE, false);
        sleep_us(DELAY_READ);

        // read from lower 8 pins, discard rest
        data[i] = gpio_get_all();

        gpio_put(OE, true);
    }

    // disable chip
    gpio_put(CE, true);

    write_all(data, 0x100);

    gpio_put(LED_RD, false);
}

/*
 * @brief Read block of 0x1000 bytes
 **/
void read_p2k_cartridge_block(uint8_t block_id) {
    gpio_put(LED_RD, true);

    // set pins 0-7 to input
    gpio_set_dir_in_masked(0x000000FF);
    
    // set pins based on block_id
    gpio_put(CE, block_id >= 2);  // CARSEL 1
    gpio_put(OE, block_id < 2);   // CARSEL 2
    unsigned int pin12 = (block_id & 1) ? 0 : (1 << 4);

    // data buffer
    uint8_t data[0x100];

    // set address to read from
    for(unsigned int j=0; j<16; j++) {
        set_address((j + pin12) << 8);
        for(unsigned int i=0; i<0x100; i++) {
            // set lower address
            set_address_low(i);

            // small delay to properly receive response
            sleep_us(DELAY_READ);

            // read from lower 8 pins, discard rest
            data[i] = gpio_get_all();
        }

        if(!write_all(data, 0x100)) {
            break;
        }
    }

    gpio_put(CE, true);
    gpio_put(OE, true);
    gpio_put(LED_RD, false);
}

/*
 * @brief Read bank of 0x4000 bytes
 **/
void read_bank(uint8_t bank_id) {
    gpio_put(LED_RD, true);

    // set pins 0-7 to input
    gpio_set_dir_in_masked(0x000000FF);
    
    // chip enable
    gpio_put(CE, false);
    gpio_put(OE, false);

    // data buffer
    uint8_t data[0x100];

    // set address to read from
    for(uint32_t j=0; j<0x40; j++) {
        set_address((j + 0x40 * bank_id) << 8);
        for(uint32_t i=0; i<0x100; i++) {
            set_address_low(i);

            sleep_us(DELAY_READ);

            // read from lower 8 pins, discard rest
            data[i] = gpio_get_all();
        }

        if(!write_all(data, 0x100)) {
            break;
        }
    }

    gpio_put(CE, true);
    gpio_put(OE, true);
    gpio_put(LED_RD, false);
}

/*
 * @brief Read sector of 0x1000 bytes
 **/
void read_sector(uint8_t sector_id) {
    gpio_put(LED_RD, true);

    // set pins 0-7 to input
    gpio_set_dir_in_masked(0x000000FF);
    
    // chip enable
    gpio_put(CE, false);
    gpio_put(OE, false);

    // data buffer
    uint8_t data[0x100];

    // set address to read from
    for(uint8_t j=0; j<0x10; j++) {
        set_address((j + 0x10 * sector_id) << 8);
        for(uint32_t i=0; i<0x100; i++) {
            set_address_low(i);

            sleep_us(DELAY_READ);

            // read from lower 8 pins, discard rest
            data[i] = gpio_get_all();
        }

        if(!write_all(data, 0x100)) {
            break;
        }
    }

    gpio_put(CE, true);
    gpio_put(OE, true);
    gpio_put(LED_RD, false);
}

/*
 * @brief Write block of 256 bytes
 *
 * sector_addr: upper bytes
 */
void write_block(uint32_t block_id) {
    // first collect all the data
    uint32_t bitsread = 0;
    uint8_t buffer[BLOCK_SIZE];
    while(bitsread < BLOCK_SIZE) {
        if(tud_cdc_available()) {
            bitsread += tud_cdc_read(&buffer[bitsread], BLOCK_SIZE - bitsread);
        }
        tud_task();
    }

    write_data(block_id << 8, buffer, BLOCK_SIZE);

    // return checksum
    uint8_t checksum = 0;
    for(uint32_t i=0; i<BLOCK_SIZE; i++) {
        checksum += buffer[i];
    }
    tud_cdc_write_char(checksum);
    tud_cdc_write_flush();
}
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

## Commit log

2023-08-07 Adding PCB images
2023-09-08 Pcbrev1 (#1)
    * Adding LEDs and putting 10k resistor on backside
    * Adding polarity protection diode and 10k resistor on backside. Adding LEDS on front side
    * Adding LEDs
    * Adding LEDs to the firmware
    [pico-sst39sf0x0-pcb-B_Cu.gbr, pico-sst39sf0x0-pcb-B_Mask.gbr, pico-sst39sf0x0-pcb-B_Paste.gbr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]
2023-09-17 Adding functionality (#3)
    * Adding adapter board for p2000t-slot1 cartridges
    * Expanding firmware and GUI to accept P2000T adapter cartridge
    * Revising P2000T adapter board to accomodate ZIF lever
    * Adding README files
    * Removing MacOS support
    * Expanding documentation
    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
    [p2000t-slot1-adapter-board-B_Cu.gbr, p2000t-slot1-adapter-board-B_Mask.gbr, p2000t-slot1-adapter-board-B_Paste.gbr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]
2023-09-24 Improving case and fixing bug in GUI (#6)
    [pico-case-bottom_mouse_ears.stl, pico-case-top_mouse_ears.stl]
2023-10-15 Adding debug log and better exception management (#8)
    * Adding debug log and better exception management
    * Adding missing files to CMakeList.txt
    * Adding header
    [main.cpp]
2023-11-12 Patch 1.3.0 (#9)
    * Adding button to completely erase a chip
    * Expanding README.md
2023-11-12 Fixing bug in board id recognition
2024-04-03 Revision 2 of the PCB (#11)
    * Initial commit revision 2
    * Revising top case
    * Updating photo
    * Updating photos PCBs
    [pico-case-top_mouse_ears.stl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]
2024-04-06 Tweaking lay-out PCB
    [pico-sst39sf0x0-pcb-B_Cu.gbr, pico-sst39sf0x0-pcb-B_Mask.gbr, pico-sst39sf0x0-pcb-B_Paste.gbr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]
2024-04-21 Version 1.4.0 (#12)
    * Initial commit TinyUSB interface
    * Improving speed of read and write routines
    * Adding switch for P2K edition
    * Initial commit Settings object
    * Adding settings widget
    * Refactoring hexviewer
    * Removing events
    * Templated installer
    * Tackling issue #10
    * Fixing templated deployment
    * Adding OSHW image
    * Set colors via settings menu
    * Implementing color themes
    * Storing last file paths
    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
    [constants.h]
2024-04-21 Adding schematics
2024-05-01 Patch v1.5.2 (#16)
    * Improving error messages
    * Incrementing version for firmware to match GUI
    [constants.h]
2024-12-22 Patch 1.6.0: Support for Raspberry Pi PICO2 (#17)
    * Initial commit Refactoring installer
    * Adding multimaterial case
    * Adding support for PICO2
    * Adding hardware ID for PICO2
    * Changing versions
    * Changing docker image
    * Fixing version
    * Changing platform
    * Fixing docker image name
    * Changing back name
    * Removing ref
    * Further removing references
    * Updating README.md
    [pico-case-bottom.stl, pico-case-bottom_mouse_ears.stl, pico-case-top.stl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]
2025-01-04 Adding case for 36mm inserts
    [pico-case-top-36.stl]
2025-01-04 Updating lay-out
    [pico-sst39sf0x0-pcb-B_Cu.gbr, pico-sst39sf0x0-pcb-B_Mask.gbr, pico-sst39sf0x0-pcb-B_Paste.gbr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]
2025-01-14 Showing multimaterial case
2026-04-12 Integrating test suite in work flow
2026-07-22 Fix silent data loss in ROM read routines (tud_cdc_write return value ignored)
    [routines.c]

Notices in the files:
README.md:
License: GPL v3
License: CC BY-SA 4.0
